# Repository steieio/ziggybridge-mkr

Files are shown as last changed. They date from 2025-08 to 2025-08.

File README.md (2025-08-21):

# Ziggy Bridge MKR

This is an adapter for boards in the Arduino MKR form factor, like some of the great low-cost FPGA boards from Trenz.

All of the 100mil pitch connectors use staggered footprints for friction fit so you can use the board without soldering.

This board adapts the MKR dual inline headers to the following connection standards:

 * 2x PMOD
 * mikroBUS Click
 * qwiic/Stemma-QT
 * Raspberry Pi UART

One of the PMOD connectors is issolated on pins D0-D7, the other is connected in parallel with the click/qwiic/uart connectors.

[Click here to view in Kicanvas](https://kicanvas.org/?github=https%3A%2F%2Fgithub.com%2Fsteieio%2Fziggybridge-mkr)

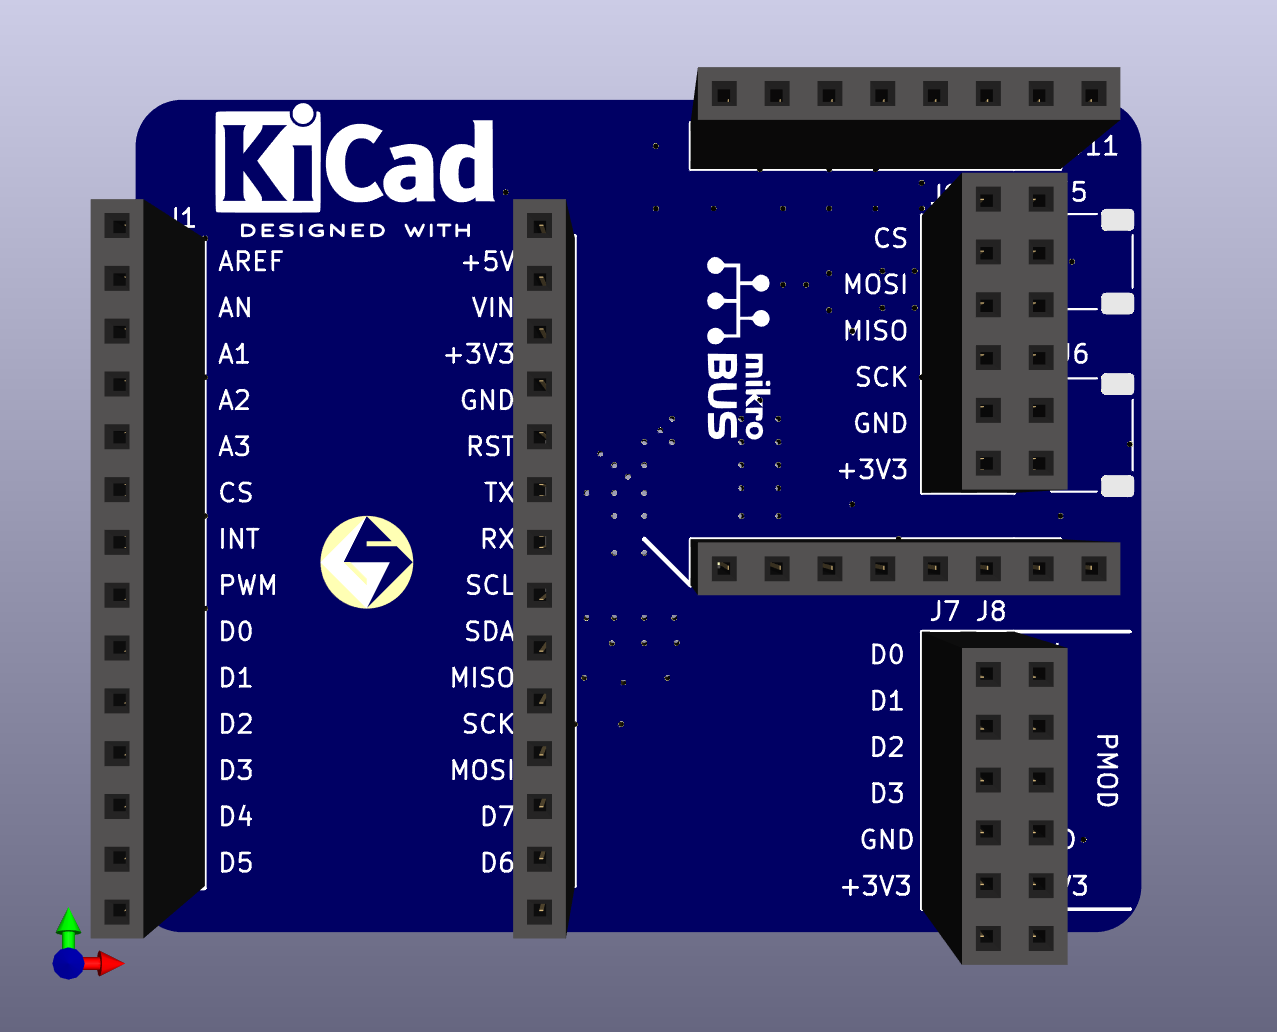
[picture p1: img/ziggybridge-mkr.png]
3D render of board


[Click here to purchase from OSH Park](https://oshpark.com/shared_projects/fBhDnFxY)
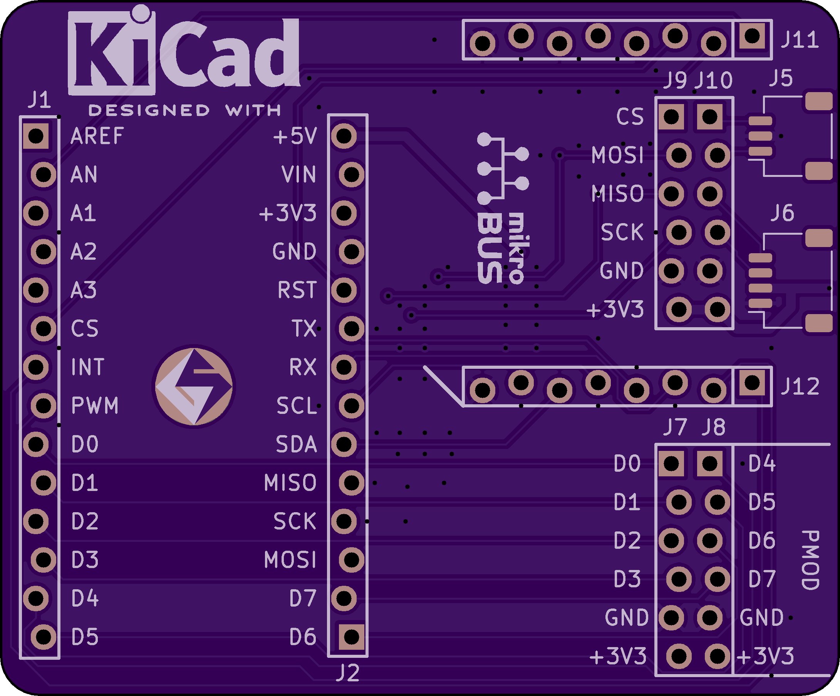
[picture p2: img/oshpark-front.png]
OshPARK front

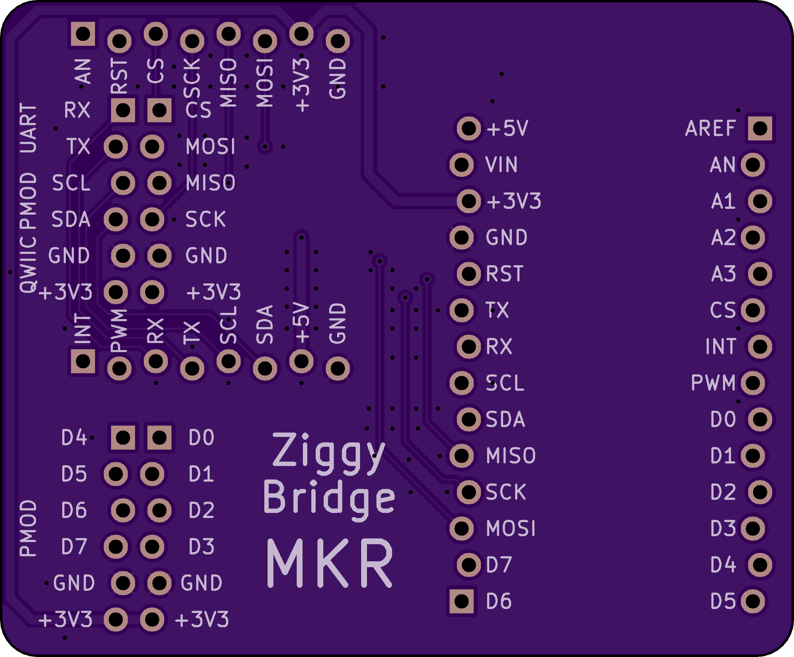
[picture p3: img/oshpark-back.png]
OshPARK back


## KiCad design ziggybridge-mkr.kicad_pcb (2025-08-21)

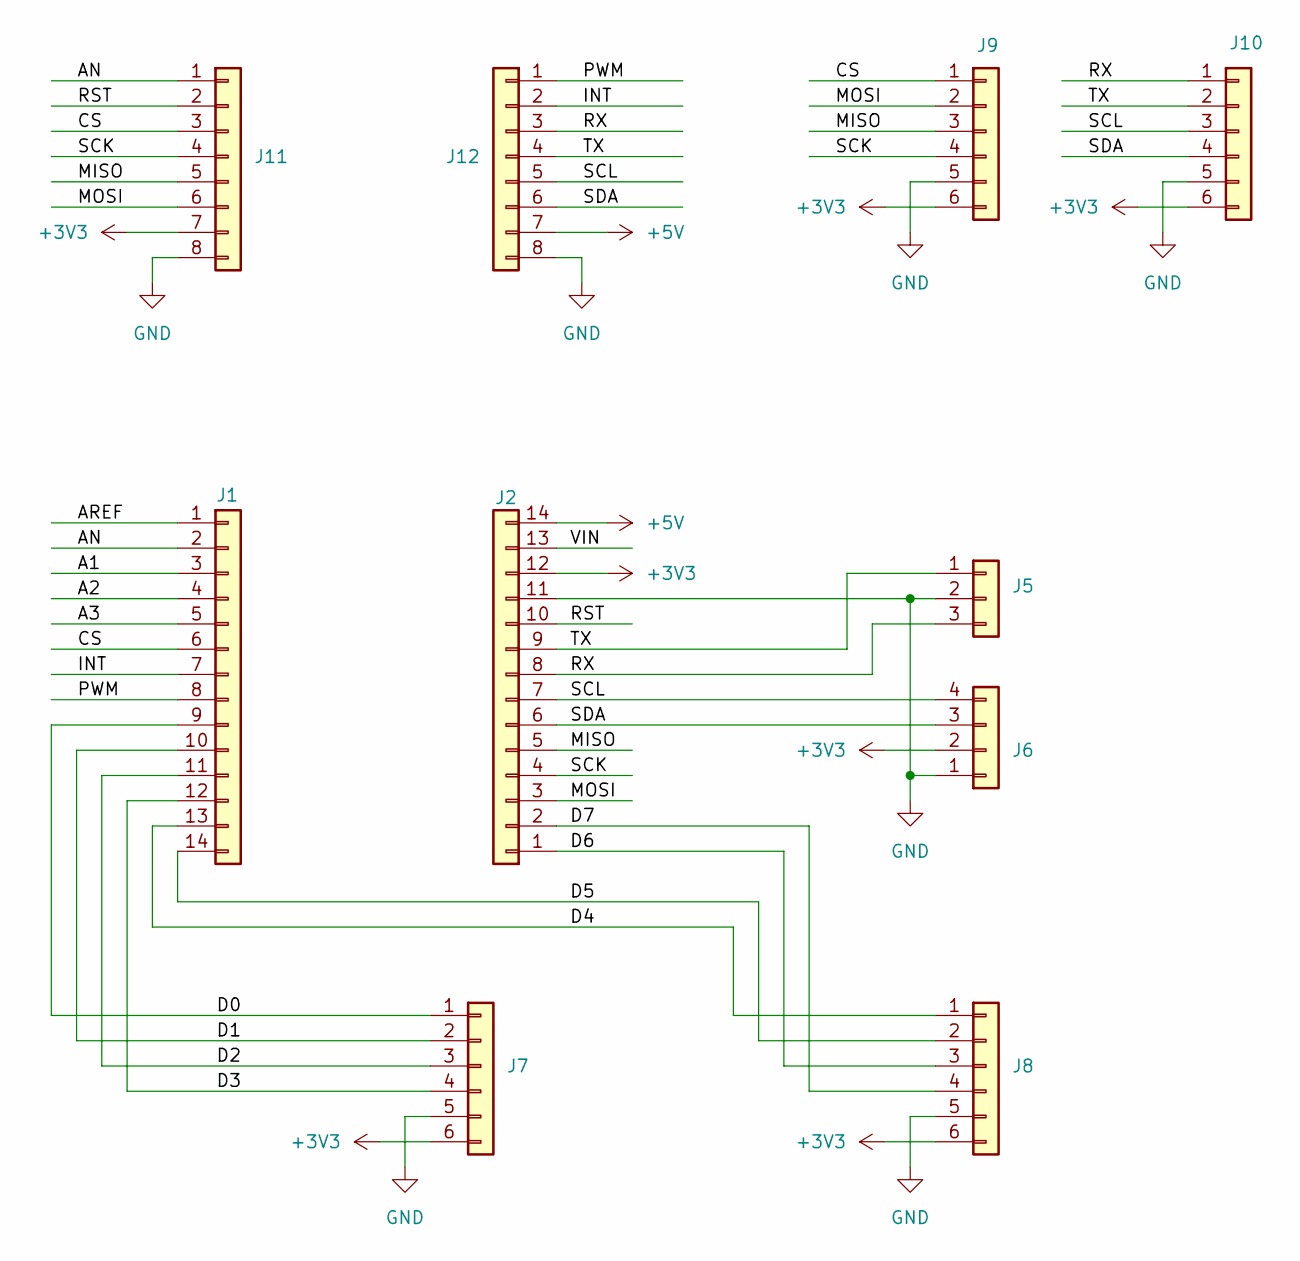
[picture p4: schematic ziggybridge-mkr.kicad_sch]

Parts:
J1, J2: Conn_01x14; PinHeader_1x14_P2.54mm_Staggered
J5: Conn_01x03; JST_SH_SM03B-SRSS-TB_1x03-1MP_P1.00mm_Horizontal
J6: Conn_01x04; JST_SH_SM04B-SRSS-TB_1x04-1MP_P1.00mm_Horizontal
J7, J8, J9, J10: Conn_01x06; PinHeader_1x06_P2.54mm_Staggered
J11, J12: Conn_01x08; PinHeader_1x08_P2.54mm_Staggered

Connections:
+3V3: J2.12, J6.2, J7.6, J8.6, J9.6, J10.6, J11.7
+5V: J2.14, J12.7
/A1: J1.3
/A2: J1.4
/A3: J1.5
/AN: J1.2, J11.1
/AREF: J1.1
/CS: J1.6, J9.1, J11.3
/D0: J1.9, J7.1
/D1: J1.10, J7.2
/D2: J1.11, J7.3
/D3: J1.12, J7.4
/D4: J1.13, J8.1
/D5: J1.14, J8.2
/D6: J2.1, J8.3
/D7: J2.2, J8.4
/INT: J1.7, J12.2
/MISO: J2.5, J9.3, J11.5
/MOSI: J2.3, J9.2, J11.6
/PWM: J1.8, J12.1
/RST: J2.10, J11.2
/RX: J2.8, J5.3, J10.1, J12.3
/SCK: J2.4, J9.4, J11.4
/SCL: J2.7, J6.4, J10.3, J12.5
/SDA: J2.6, J6.3, J10.4, J12.6
/TX: J2.9, J5.1, J10.2, J12.4
/VIN: J2.13
GND: J2.11, J5.2, J6.1, J7.5, J8.5, J9.5, J10.5, J11.8, J12.8

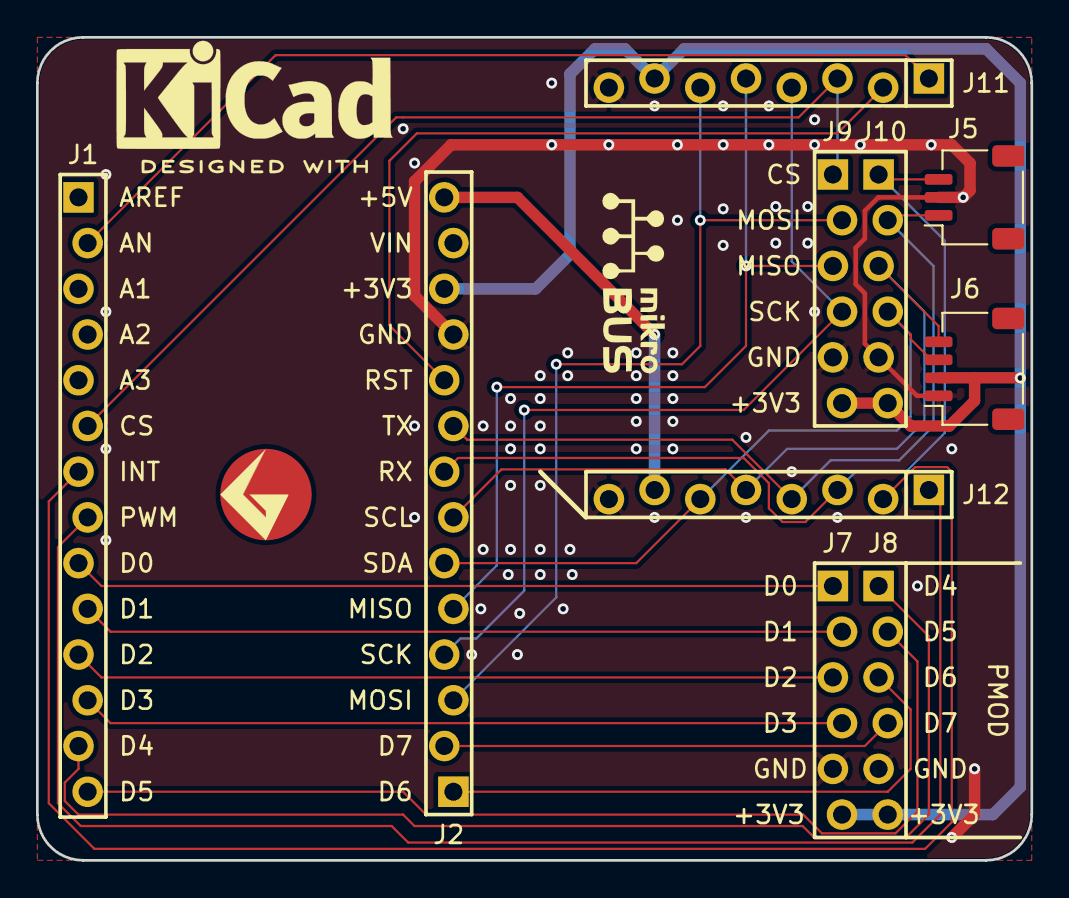
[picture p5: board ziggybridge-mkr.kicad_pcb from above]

Board: 2 copper layers, 55.2 x 45.7 mm, 11 parts (0 on the bottom side), 23 nets.

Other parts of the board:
GS1: GS_logo; gs_logo_200mil

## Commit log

2025-07-30 chekcing in fully routed board
    [ziggybridge-mkr.kicad_pcb, ziggybridge-mkr.kicad_sch]
2025-07-30 fixed labels on MKR socket
    [ziggybridge-mkr.kicad_pcb]
2025-07-30 changed to 2 layers
    [ziggybridge-mkr.kicad_pcb]
2025-08-21 cleaned up design, removed soldermask adjustments and wide ground traces that were defeating thermal releifs
    [ziggybridge-mkr.kicad_pcb]
